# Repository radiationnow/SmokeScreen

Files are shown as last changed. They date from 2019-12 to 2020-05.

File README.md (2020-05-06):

# SmokeScreen
SmokeScreen is a NodeMCU/ESP32-based smoker temperature monitor/controller using MQTT for communication.

(Well, it'll be a controller some day.  For now, just a monitor.)

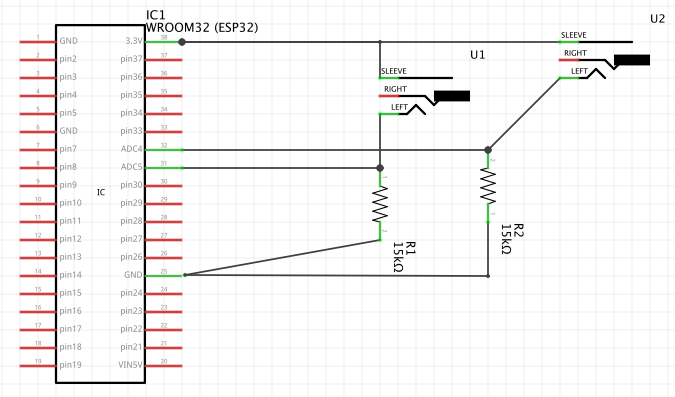
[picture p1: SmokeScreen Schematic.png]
SmokeScreen Schematic


Simple circuit: NodeMCU ESP32 board, 2x 15k resistors to form the bottom leg of voltage dividers, and a pair of panel mount 2.5mm TS (mono) jacks.  (Fritzing only had stereo, but use mono.) 

Probe coefficients are hand calibrated using a known-good instant read thermometer, an ice bath, a warm bath, and a boiling bath.  Probes tested with include Thermoworks High Temp Air, Thermoworks normal probe, and a clone ET-733 probe.  Pit thermistor voltage divider center measured on pin 32, meat thermistor on pin 33.

Loosely inspired by CapnBry's HeaterMeter - https://github.com/CapnBry/HeaterMeter/.

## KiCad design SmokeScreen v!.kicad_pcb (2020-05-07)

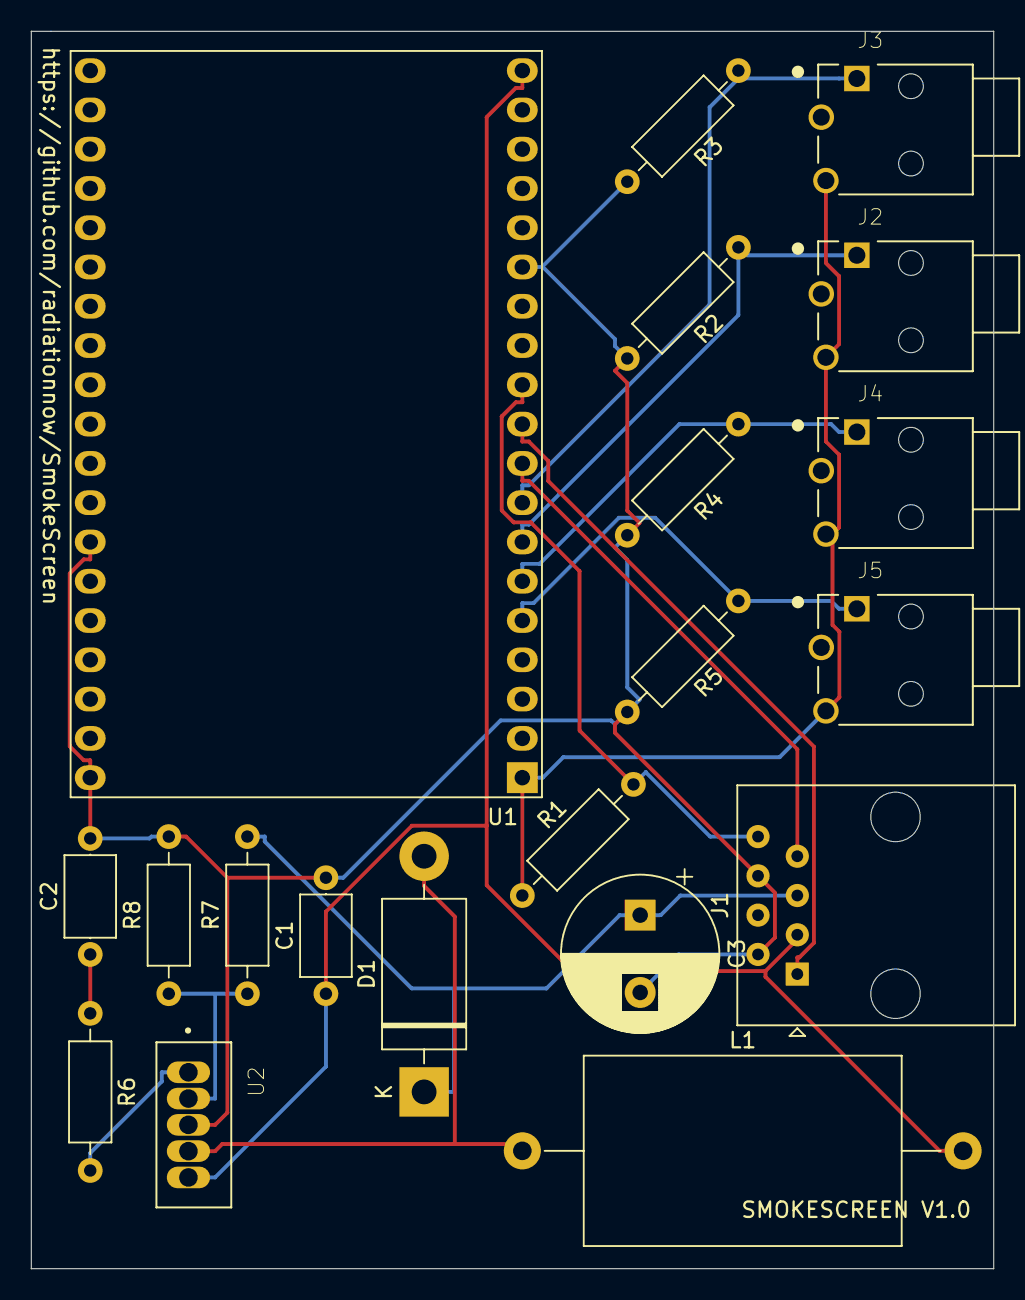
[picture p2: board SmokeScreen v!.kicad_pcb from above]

Board: 2 copper layers, 62.2 x 80.0 mm, 20 parts (0 on the bottom side), 15 nets.

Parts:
C1: 0.1uF; C_Axial_L5.1mm_D3.1mm_P7.50mm_Horizontal
C2: .33uF; C_Axial_L5.1mm_D3.1mm_P7.50mm_Horizontal
C3: 680uF; CP_Radial_D10.0mm_P5.00mm
D1: 1N5821; D_DO-201AD_P15.24mm_Horizontal
J1: 8P8C; RJ45_Amphenol_54602-x08_Horizontal
J2, J3, J4, J5: MJ-2509N; CUI_MJ-2509N
L1: 100uH; L_Axial_L20.3mm_D12.1mm_P28.50mm_Horizontal_Vishay_IHA-101
R1: 4.7K; R_Axial_DIN0207_L6.3mm_D2.5mm_P10.16mm_Horizontal
R2, R3, R4, R5: 15K; R_Axial_DIN0207_L6.3mm_D2.5mm_P10.16mm_Horizontal
R6: 2.2K; R_Axial_DIN0207_L6.3mm_D2.5mm_P10.16mm_Horizontal
R7: 17.4K; R_Axial_DIN0207_L6.3mm_D2.5mm_P10.16mm_Horizontal
R8: 2K; R_Axial_DIN0207_L6.3mm_D2.5mm_P10.16mm_Horizontal
U1: NodeMCU_ESP-32S; NodeMCU-ESP32S
U2: LM2577T-12; VREG_LM2577T-12

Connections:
/FANPWM: J1.7, U1.9
/FAN_12V: C3.1, D1.1, J1.5, R7.2
/SERVO_PWM: J1.1, U1.10
/SERVO_VCC: C1.1, J1.3, L1.2, U1.19, U2.5
/TACH: J1.8, R1.2, U1.11
GND: C1.2, C2.2, C3.2, J1.2, J1.6, R2.2, R3.2, R4.2, R5.2, R8.2, U1.14, U1.32, U1.38, U2.3
unnamed: C2.1, R6.1
unnamed: D1.2, L1.1, U2.4
unnamed: J2.1, R2.1, U1.7
unnamed: J2.3, J3.3, J4.3, J5.3, R1.1, U1.1
unnamed: J3.1, R3.1, U1.8
unnamed: J4.1, R4.1, U1.6
unnamed: J5.1, R5.1, U1.5
unnamed: R6.2, U2.1
unnamed: R7.1, R8.1, U2.2

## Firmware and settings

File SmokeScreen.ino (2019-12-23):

#include "EspMQTTClient.h"
#include "secrets.h"

//Pins
#define PITPIN 32
#define MEAT1PIN 33

// resistor definition for ET733 probes - maybe don't need to use a 1M resistor for ET733?
// #define PITRESISTOR 992500 

// resistor definition for 10k probes like Thermoworks
//#define PITRESISTOR 9870
#define PITRESISTOR 14750
#define MEATRESISTOR1 14890

#define MQTT_TOPIC "smokescreen"
#define OVERSAMPLE 8

// interval between control loops in milliseconds
#define CTRL_INTERVAL 500

// interval between automatic temperature updates via MQTT in milliseconds
#define REPORT_INTERVAL 10000

// Temp equation definitions for ET733 - hand calibrated
#define A_ET733 -0.0034058161844664142
#define B_ET733 0.0005973859341993963
#define C_ET733 -5.875837340570243e-7

// Temp equation definitions for Thermoworks probes - taken from HeaterMeter by CapnBry
//#define A_THERM 7.3431401e-4
//#define B_THERM 2.1574370e-4
//#define C_THERM 9.5156860e-8

// Temp equations for Thermoworks probes, hand calibrated
#define A_THERM 0.00047630463092729856
#define B_THERM 0.00024773576511516335
#define C_THERM -6.407966149699128e-9

// Network info setup
// Array of resistor pins; array is indexed -32, so pin 32 is array entry 0 (default is pit pin on 32), pin 33 is entry 1, etc.
const int pinresistor[2] = {PITRESISTOR, MEATRESISTOR1};

const char* ssid = WIFI_SSID;
const char* password = WIFI_PW;
const char* mqtt_server = MQTT_IP;
const char* mqtt_username = MQTT_USER;
const char* mqtt_password = MQTT_PW;
const char* mqtt_clientid = "smokescreen";
const short mqtt_port = 1883;

EspMQTTClient client(
    ssid,
    password,
    mqtt_server,
    mqtt_username,
    mqtt_password,
    mqtt_clientid,
    mqtt_port
);

unsigned long lastMsg = 0;
#define MSG_BUFFER_SIZE (50)
char msg[MSG_BUFFER_SIZE];
int value = 0;
unsigned long previousMillis = 0;
unsigned long reportMillis = 0;
const long interval = CTRL_INTERVAL;
const long report_interval = REPORT_INTERVAL;
float setpoint = 100.0;
float pid_p = 4;
float pid_i = 0.01;
float pid_d = 0.0;

void cmd_callback(const String &payload) {
  String tvar, out;
  Serial.print("Message arrived on SmokeScreen/commands ");
  Serial.print(payload);
  Serial.println();
  tvar = payload;
  tvar.remove(0, 8);
  if (payload.startsWith("settemp ")) {
    Serial.print("Setting temperature to ");
    Serial.println(payload);
    setpoint = tvar.toFloat(); // strip settemp command, leaving only temperature
  } else if (payload.startsWith("setpidP ")) {
    Serial.print("Setting PID P value to ");
    Serial.println(payload);
    pid_p = tvar.toFloat(); // strip setpidP command, leaving only P value
  } else if (payload.startsWith("setpidI ")) {
    Serial.print("Setting PID P value to ");
    Serial.println(payload);
    pid_i = tvar.toFloat(); // strip setpidI command, leaving only I value
  } else if (payload.startsWith("setpidD ")) {
    Serial.print("Setting PID P value to ");
    Serial.println(payload);
    pid_d = tvar.toFloat(); // strip setpidD command, leaving only D value
  } else if (payload.startsWith("getpidP ")) {
    Serial.print("PID P value is ");
    Serial.println(pid_p);
    out = "pidPval " + String(pid_p,4);
    client.publish("SmokeScreen/data", out);
  } else if (payload.startsWith("getpidI ")) {
    Serial.print("PID I value is ");
    Serial.println(pid_i);
    out = "pidIval " + String(pid_i,4);
    client.publish("SmokeScreen/data", out);
  } else if (payload.startsWith("getpidD ")) {
    Serial.print("PID D value is ");
    Serial.println(pid_d);
    out = "pidDval " + String(pid_d,4);
    client.publish("SmokeScreen/data", out);
  }
}

void cmd_callback_pit(const String &payload) {
  Serial.print("Message arrived on SmokeScreen/commands/pit ");
  Serial.print(payload);
  Serial.println();
  if (payload.startsWith("gettemp")) {
    Serial.print("Getting pit temperature: ");
    Serial.println(payload);
    client.publish("SmokeScreen/data/pit", "temp " + String(get_temp(PITPIN),3));
  }
}

void cmd_callback_meat1(const String &payload) {
  Serial.print("Message arrived on SmokeScreen/commands/meat1 ");
  Serial.print(payload);
  Serial.println();
  if (payload.startsWith("gettemp ")) {
    Serial.print("Getting meat probe 1 temperature: ");
    Serial.println(payload);
    client.publish("SmokeScreen/data/meat1", "temp " + String(get_temp(MEAT1PIN),3));
  }
}

void setup() {
  // put your setup code here, to run once:
  Serial.begin(115200);
  client.enableDebuggingMessages();
  previousMillis = millis();
}


float adc2temp(int adcval) {

  float R, ln, TInv, temp;

  // coefficients for temp calc, ET733 probe
//  float A = A_ET733;
//  float B = B_ET733;
//  float C = C_ET733;

  // coefficients for temp calc, Thermoworks probe
  float A = A_THERM;
  float B = B_THERM;
  float C = C_THERM;

  R = PITRESISTOR * (4095.0 / adcval - 1);

  // temp calc
  ln = log(R);
  TInv = A + B*ln + C*pow(ln, 3);
  temp = 1.8*(1.0/TInv - 273.15) + 32.0;

  return temp;
}

void onConnectionEstablished() {
  // client.subscribe("SmokeScreen/commands", [](const String & payload) { cmd_callback(payload); });
  client.subscribe("SmokeScreen/commands", cmd_callback);
  client.subscribe("SmokeScreen/commands/pit", cmd_callback_pit);
  client.subscribe("SmokeScreen/commands/meat1", cmd_callback_meat1);
  client.publish("SmokeScreen/data", "smokescreen connected");
}

void loop() {
  unsigned long currentMillis = millis();
  
  while (currentMillis - previousMillis <= CTRL_INTERVAL) 
    {
      client.loop();
      currentMillis = millis();
    }
  previousMillis = currentMillis;

  // temp measurement code
  int pitadc, meatadc;
  float pittemp, meat1temp;
  char tempstring[20];

  pittemp = get_temp(PITPIN);
  meat1temp = get_temp(MEAT1PIN);

  if (currentMillis - reportMillis >= REPORT_INTERVAL) {
    Serial.println("REPORTING");
    reportMillis = currentMillis;
    client.publish("SmokeScreen/status/pittemp", String(pittemp,3));
    client.publish("SmokeScreen/status/meat1temp", String(meat1temp,3));
  }
//  delay(1000);
}

int getADC(int pinnum) {

  double pinSamples[OVERSAMPLE];
  double average;
  int i;

  // Collect oversampled number of samples
  for (i=0; i<OVERSAMPLE; i++) {
    pinSamples[i] = analogRead(pinnum);
    delay(10);
  }

// sum the raw oversampled samples
  average = 0;
  for (i=0; i<OVERSAMPLE; i++){
    average += pinSamples[i];
  }
  
// divide by number of oversamples to obtain higher accuracy result
  average /= OVERSAMPLE;
  return average;
}

float get_temp(int pinnum) {
  
  int pinadc;
  double pinvolt;
  float R, pintemp;
  
  // get oversampled ADC
  pinadc = getADC(pinnum);

  // temp calc
  pintemp = adc2temp(pinadc);

  // estimate raw voltage at ADC - only used for debug
  pinvolt = pinadc*3.3;
  pinvolt = pinvolt / 4096.0;
  // convert ADC output to resistance estimate - only needed for debug
  R = pinresistor[pinnum - 32] * (4095.0 / pinadc - 1);
  // serial output of ADC for debug
//  Serial.print("Pin ");
//  Serial.print(pinnum);
//  Serial.print(" ADC val: ");
//  Serial.println(pinadc);
//  Serial.print("Pin ");
//  Serial.print(pinnum);
//  Serial.print(" ADC voltage: ");
//  Serial.println(pinvolt);
//  Serial.print("Pin ");
//  Serial.print(pinnum);
//  Serial.print(" thermistor ohms: ");
//  Serial.println(R);
//  Serial.print("Pin ");
//  Serial.print(pinnum);
//  Serial.print ("estimated temp: ");
//  Serial.print(pintemp);
//  Serial.println(" F");
  return pintemp;
}

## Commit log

2020-05-06 Add schematic image to readme.
2020-05-07 UNTESTED long-term plan schematic/PCB
    KiCad schematic and PCB file for a 4-channel version with PWMed blower and servo damper support over a single Ethernet cable. Uses a single 5V supply to drive everything, includes a 12V boost convert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
    THIS DESIGN IS UNTESTED AND SOFTWARE DOES NOT YET SUPPORT.
    [SmokeScreen v!.kicad_pcb, SmokeScreen v!.sch]
